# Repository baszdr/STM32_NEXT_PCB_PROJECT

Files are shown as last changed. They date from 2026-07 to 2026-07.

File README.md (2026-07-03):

# STM32_NEXT_PCB_PROJECT
Designed a compact embedded system integrating USB-C, power management, and RF design into a single 4-layer PCB. Focused on clean layout, strong signal integrity, and practical debugging structure. 
💡 Features: 
• STM32WB55 (BLE)
• USB-C with protection
• 3.3V regulation 
• RF matching + U.FL • SWD debugging  
🤝 Sponsored by NextPCB "https://www.nextpcb.com
"

<div align="center">
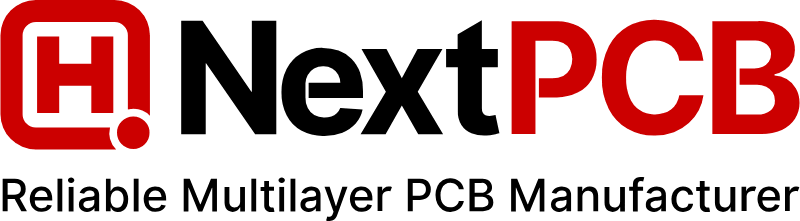
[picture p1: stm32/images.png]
STM32 NEXT PCB Project
  
</div>

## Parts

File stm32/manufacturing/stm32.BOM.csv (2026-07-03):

Source: | C:\Users\smbna\OneDrive - Rīgas Tehniskā Universitāte\Dokumenti\KiCad\stm32\stm32.kicad_sch
Date: | 2026-04-02T17:49:33+0300
Tool: | Eeschema 9.0.7
Generator: | C:\Program Files\KiCad\9.0\bin\scripting\plugins/bom_csv_grouped_by_value_with_fp.py
Component Count: | 48
Ref | Qnty | Value | Cmp name | Footprint | Description | Vendor | DNP
C1, C2, C3, C4, C5, C6, C8, C9, C10, C12, C17 | 11 | 100n | C | Capacitor_SMD:C_0402_1005Metric | Unpolarized capacitor
C7 | 1 | 4u7 | C | Resistor_SMD:R_0402_1005Metric | Unpolarized capacitor
C11, C13 | 2 | 10P | C | Capacitor_SMD:C_0402_1005Metric | Unpolarized capacitor
C14, C18, C19 | 3 | 4u7 | C | Capacitor_SMD:C_0603_1608Metric | Unpolarized capacitor
C15 | 1 | op8 | C | Capacitor_SMD:C_0402_1005Metric | Unpolarized capacitor
C16 | 1 | op3 | C | Capacitor_SMD:C_0402_1005Metric | Unpolarized capacitor
D1 | 1 | LED | LED | Inductor_SMD:L_0402_1005Metric | Light emitting diode
FLT1 | 1 | DLF162500 | DLF162500LT | BLUEPRINT:Untitled
FM1, FM2, FM3 | 3 | Fiducial | Fiducial | Fiducial:Fiducial_1mm_Mask2mm | Fiducial Marker
H1, H2, H3, H4 | 4 | MountingHole_Pad | MountingHole_Pad | MountingHole:MountingHole_2.2mm_M2_Pad_Via | Mounting Hole with connection
J1 | 1 | USB_C_Receptacle_USB2.0_16P | USB_C_Receptacle_USB2.0_16P | Connector_USB:USB_C_Receptacle_GCT_USB4105-xx-A_16P_TopMnt_Horizontal | USB 2.0-only 16P Type-C Receptacle connector
J2 | 1 | Conn_01x04 | Conn_01x04 | Connector_Molex:Molex_CLIK-Mate_502386-0470_1x04-1MP_P1.25mm_Horizontal | Generic connector, single row, 01x04, script generated (kicad-library-utils/schlib/autogen/connector/)
J3 | 1 | ~ | Conn_ARM_SWD_TagConnect_TC2030 | Connector:Tag-Connect_TC2030-IDC-FP_2x03_P1.27mm_Vertical | Tag-Connect ARM Cortex SWD JTAG connector, 6 pin
J4 | 1 | Conn_Coaxial | Conn_Coaxial | Connector_Coaxial:U.FL_Hirose_U.FL-R-SMT-1_Vertical | coaxial connector (BNC, SMA, SMB, SMC, Cinch/RCA, LEMO, ...)
L1 | 1 | 10n | L | Inductor_SMD:L_0402_1005Metric | Inductor
L2 | 1 | 10u | L | Inductor_SMD:L_0402_1005Metric | Inductor
L3 | 1 | 2n7 | L | Inductor_SMD:L_0402_1005Metric | Inductor
R1, R2 | 2 | 51k | R | Resistor_SMD:R_0402_1005Metric | Resistor
R3, R4, R5, R7 | 4 | 220R | R | Resistor_SMD:R_0402_1005Metric | Resistor
R6 | 1 | 5k1 | R | Resistor_SMD:R_0402_1005Metric | Resistor
SW1 | 1 | SW_Push | SW_Push | Button_Switch_SMD:SW_SPST_CK_RS282G05A3 | Push button switch, generic, two pins
U1 | 1 | USBLC6-2SC6 | USBLC6-2SC6 | Package_TO_SOT_SMD:SOT-23-6 | Very low capacitance ESD protection diode, 2 data-line, SOT-23-6
U2 | 1 | STM32WB55CEU6 | STM32WB55CEUx | Package_DFN_QFN:QFN-48-1EP_7x7mm_P0.5mm_EP5.6x5.6mm | STMicroelectronics Arm Cortex-M4 MCU, 512KB flash, 256KB RAM, 64 MHz, 1.71-3.6V, 30 GPIO, UFQFPN48
U3 | 1 | MIC5365-3.3YD5 | MIC5365-3.3YD5 | Package_TO_SOT_SMD:TSOT-23-5 | 150mA Low-dropout Voltage Regulator, Vout 3.3V, Vin up to 5.5V, TSOT-23-5
X1 | 1 | Crystal | Crystal | Crystal:Crystal_SMD_2012-2Pin_2.0x1.2mm | Two pin crystal
Y1 | 1 | Crystal_GND24 | Crystal_GND24 | Crystal:Crystal_SMD_2016-4Pin_2.0x1.6mm | Four pin crystal, GND on pins 2 and 4

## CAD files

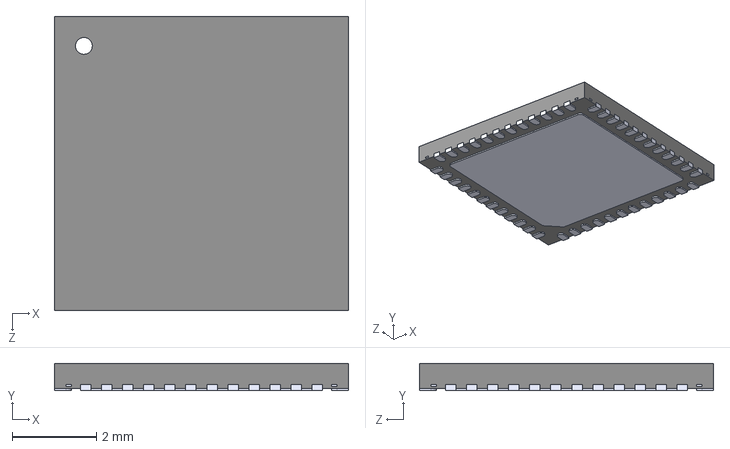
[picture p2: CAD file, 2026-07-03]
stm32/STM32WB55CEU6TR.STEP
7.00 x 0.65 x 7.00 mm

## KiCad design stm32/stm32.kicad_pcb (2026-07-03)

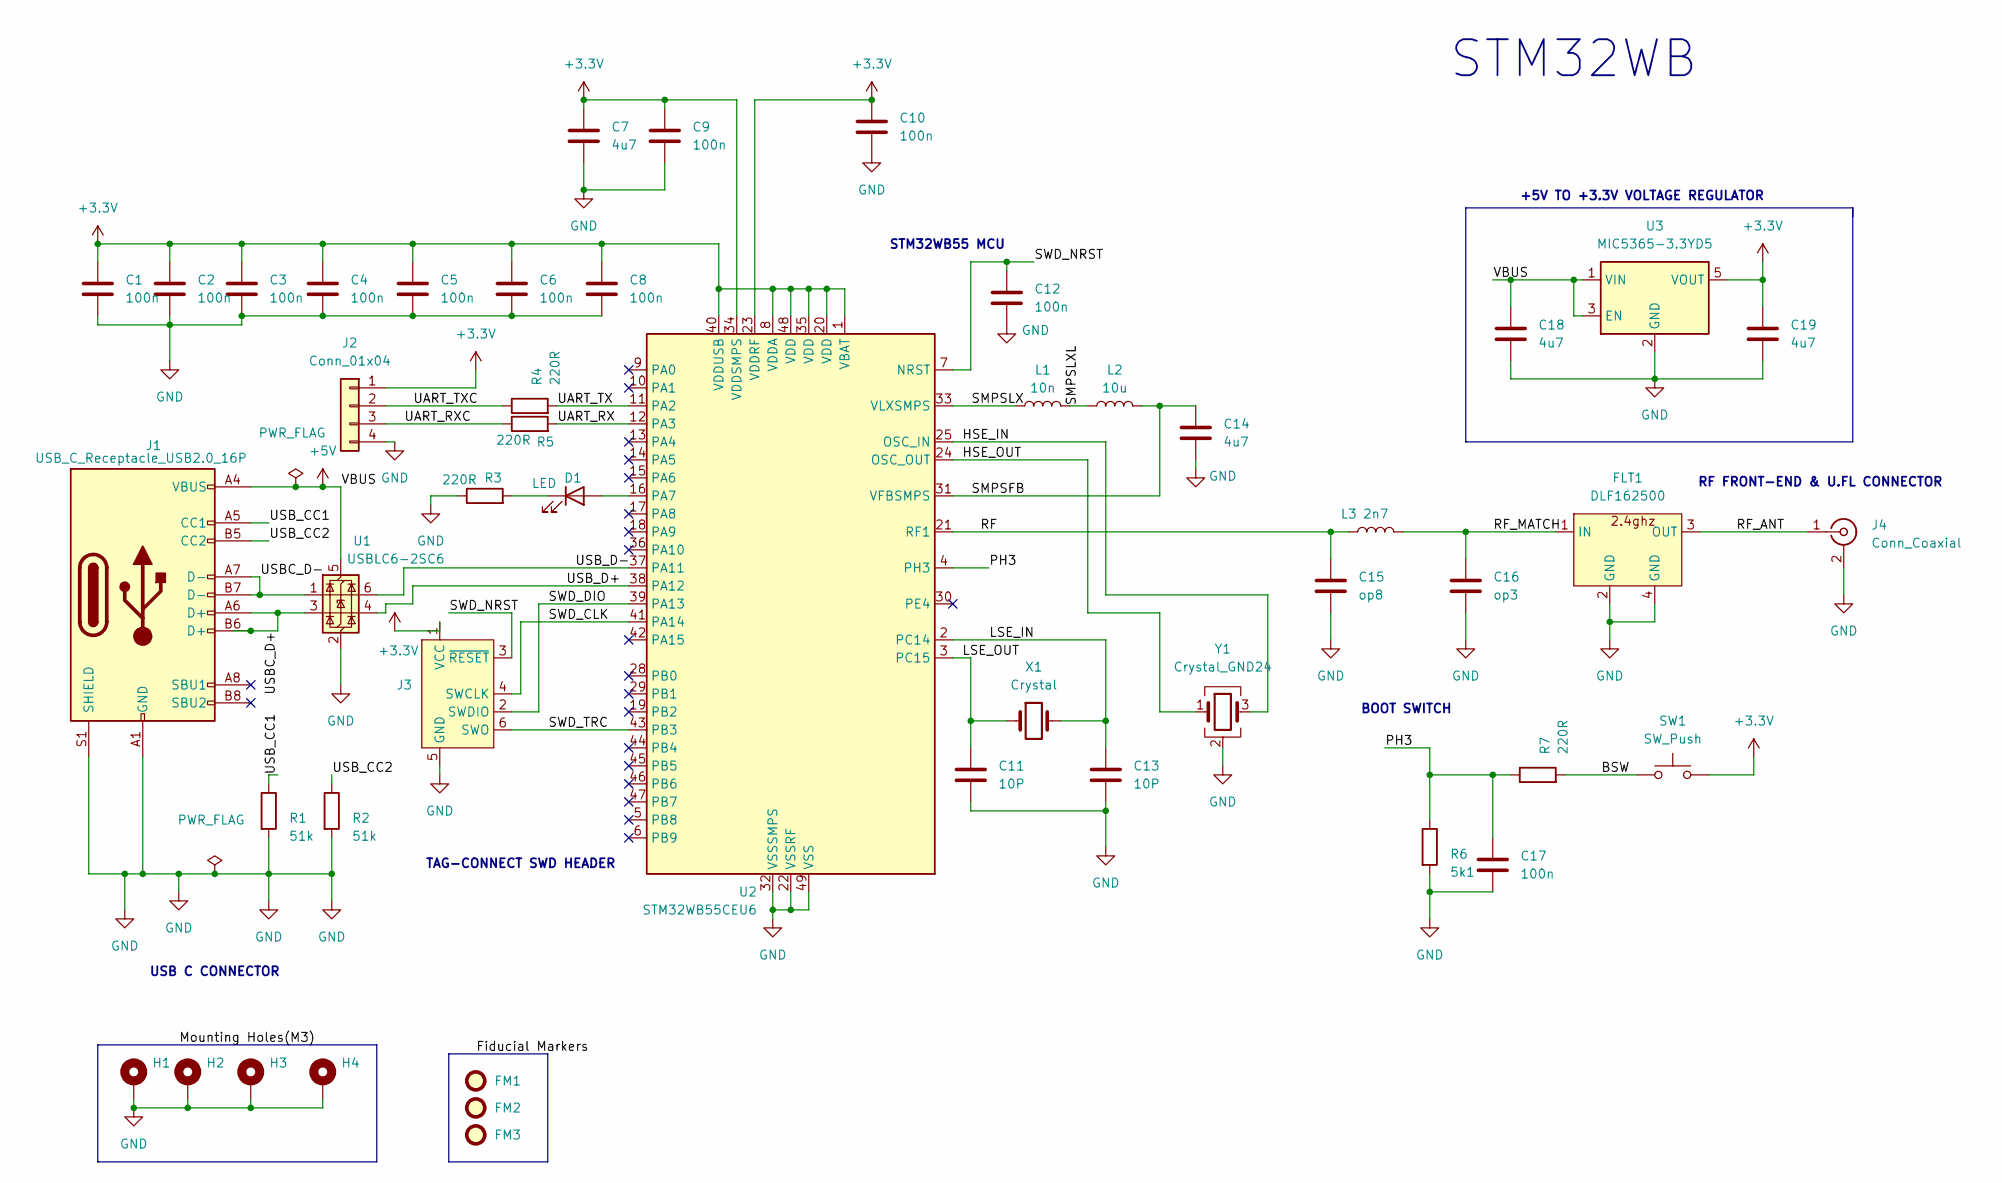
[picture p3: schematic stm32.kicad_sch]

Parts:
C1, C2, C3, C4, C5, C6, C8, C9, C10, C12, C17: 100n; C_0402_1005Metric
C7: 4u7; R_0402_1005Metric
C11, C13: 10P; C_0402_1005Metric
C14, C18, C19: 4u7; C_0603_1608Metric
C15: op8; C_0402_1005Metric
C16: op3; C_0402_1005Metric
D1: LED; L_0402_1005Metric
FLT1: DLF162500; Untitled
FM1, FM2, FM3: Fiducial; Fiducial_1mm_Mask2mm
H1, H2, H3, H4: MountingHole_Pad; MountingHole_2.2mm_M2_Pad_Via
J1: USB_C_Receptacle_USB2.0_16P; USB_C_Receptacle_GCT_USB4105-xx-A_16P_TopMnt_Horizontal
J2: Conn_01x04; Molex_CLIK-Mate_502386-0470_1x04-1MP_P1.25mm_Horizontal
J3: Tag-Connect_TC2030-IDC-FP_2x03_P1.27mm_Vertical
J4: Conn_Coaxial; U.FL_Hirose_U.FL-R-SMT-1_Vertical
L1: 10n; L_0402_1005Metric
L2: 10u; L_0402_1005Metric
L3: 2n7; L_0402_1005Metric
R1, R2: 51k; R_0402_1005Metric
R3, R4, R5, R7: 220R; R_0402_1005Metric
R6: 5k1; R_0402_1005Metric
SW1: SW_Push; SW_SPST_CK_RS282G05A3
U1: USBLC6-2SC6; SOT-23-6
U2: STM32WB55CEU6; QFN-48-1EP_7x7mm_P0.5mm_EP5.6x5.6mm
U3: MIC5365-3.3YD5; TSOT-23-5
X1: Crystal; Crystal_SMD_2012-2Pin_2.0x1.2mm
Y1: Crystal_GND24; Crystal_SMD_2016-4Pin_2.0x1.6mm

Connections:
+3.3V: C1.1, C2.1, C3.1, C4.1, C5.1, C6.1, C7.1, C8.1, C9.1, C10.1, C19.1, J2.1, J3.1 (VCC), SW1.2, U2.1 (VBAT), U2.8 (VDDA), U2.20 (VDD), U2.23 (VDDRF), U2.34 (VDDSMPS), U2.35 (VDD), U2.40 (VDDUSB), U2.48 (VDD), U3.5 (VOUT)
+5V: C18.1, J1.A4 (VBUS), J1.A9 (VBUS), J1.B4 (VBUS), J1.B9 (VBUS), U1.5 (VBUS), U3.1 (VIN), U3.3 (EN)
/BSW: R7.2, SW1.1
/HSE_IN: U2.25 (OSC_IN), Y1.3
/HSE_OUT: U2.24 (OSC_OUT), Y1.1
/LSE_IN: C13.1, U2.2 (PC14), X1.2
/LSE_OUT: C11.1, U2.3 (PC15), X1.1
/PH3: C17.1, R6.1, R7.1, U2.4 (PH3)
/RF: C15.1, L3.1, U2.21 (RF1)
/RF_ANT: FLT1.3 (OUT), J4.1 (In)
/RF_MATCH: C16.1, FLT1.1 (IN), L3.2
/SMPSFB: C14.1, L2.2, U2.31 (VFBSMPS)
/SMPSLX: L1.1, U2.33 (VLXSMPS)
/SMPSLXL: L1.2, L2.1
/SWD_CLK: J3.4 (SWCLK), U2.41 (PA14)
/SWD_DIO: J3.2 (SWDIO), U2.39 (PA13)
/SWD_NRST: C12.1, J3.3 (~RESET), U2.7 (NRST)
/SWD_TRC: J3.6 (SWO), U2.43 (PB3)
/UART_RX: R5.2, U2.12 (PA3)
/UART_RXC: J2.3, R5.1
/UART_TX: R4.2, U2.11 (PA2)
/UART_TXC: J2.2, R4.1
/USBC_D+: J1.A6 (D+), J1.B6 (D+), U1.3 (I/O2)
/USBC_D-: J1.A7 (D-), J1.B7 (D-), U1.1 (I/O1)
/USB_CC1: J1.A5 (CC1), R1.1
/USB_CC2: J1.B5 (CC2), R2.1
/USB_D+: U1.4 (I/O2), U2.38 (PA12)
/USB_D-: U1.6 (I/O1), U2.37 (PA11)
GND: C1.2, C2.2, C3.2, C4.2, C5.2, C6.2, C7.2, C8.2, C9.2, C10.2, C11.2, C12.2, C13.2, C14.2, C15.2, C16.2, C17.2, C18.2, C19.2, FLT1.2 (GND), FLT1.4 (GND), H1.1, H2.1, H3.1, H4.1, J1.A1 (GND), J1.A12 (GND), J1.B1 (GND), J1.B12 (GND), J1.S1 (SHIELD), J2.4, J3.5 (GND), J4.2 (Ext), R1.2, R2.2, R3.1, R6.2, U1.2 (GND), U2.22 (VSSRF), U2.32 (VSSSMPS), U2.49 (VSS), U3.2 (GND), Y1.2 (G), Y1.4 (G)
unnamed: D1.2 (A), U2.16 (PA7)
unnamed: D1.1 (K), R3.2

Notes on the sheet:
+5V TO +3.3V VOLTAGE REGULATOR
RF FRONT-END & U.FL CONNECTOR
TAG-CONNECT SWD HEADER
USB C CONNECTOR
STM32WB
STM32WB55 MCU
BOOT SWITCH

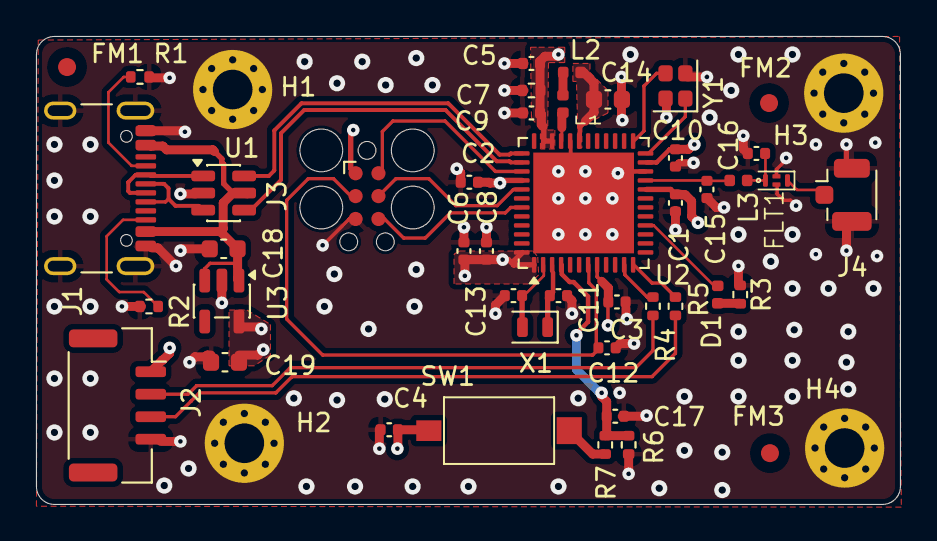
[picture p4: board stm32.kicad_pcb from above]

Board: 4 copper layers, 48.0 x 26.0 mm, 48 parts (0 on the bottom side), 31 nets.

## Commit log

2026-07-03 Upload KiCad design with all folders
    [clock_with_Led.kicad_pcb, clock_with_Led.kicad_sch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]
2026-07-03 Add test_work_5 for Kicad software practice
    This file includes the test work 5 of the practising work of Kicad software
